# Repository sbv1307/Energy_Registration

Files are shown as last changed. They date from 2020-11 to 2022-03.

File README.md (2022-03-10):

# **Energy registration**
###### **Version 2.0.0**

This Arduino project will monitor the open collector output on a number of Carlo Gavazzi energy meters Type EM23 DIN and/or Type EM111.
The pulses will be counted and turned into number of kilo watt hours (kWh).

Upon request, the pulses counted (presented in kWh) will be pushed to a Google Sheet through a local webhook (A web site which basically "translate" HPPT to HTTPS).

Each meter monitored, will be connected to a digital imput, as well as the interrupt pin (See Emergy Registration Schematics.pdf for details).

Upon a HTTP GET pushToGoogle request (http://<Arduino IP address>/pushToGoogle), the sketch will return a HTML webpage, showing the current meter valeus, 
and initiate a HTTP GET request towards a local webHook, with the meter values, as the GET query values.

A HTTP GET meterValue request (http://<Arduino IP address>/meterValue) will return a webpage showing the current meter valeus.
 
A HTTP GET meterValue?meter<n>=<nn>, will set the counter to the provided value for the specified energy meter.
The value <n> represent the energy meter 1-7 and nn the actual energy meter value as readden on the meter, with two dicmals but entered without the decimal seperator!
(http://<Arduino IP address>/meterValue?meter1=1234567 will set the value for energy meter number one to 12345.67)

Notes:
The sketch monitors interrupt pin 2 for a FALLING puls and then reads the defined channelPins and register pulses for each pin.
The interruptfunction has a catch: It enters a "while pin 2 is low" loop, and stays there, until the interrupt is released.
This is against all recomendations, saying Interruptfunctions should be very short. 

However, in order to handle the problem with overlapping pulses from more meters, the interruptfunction will read the channels over and over,
without re-reading channels that allready has been read active (low). This way all pulses on all channels will be read.

Example: Tree meters generate tree pulses as shown below:
```bash
          _______        _______
Meter #1:        |______|
             _______        _______
Meter #2:           |______|
                _______        _______
Meter #3:              |______|

```
A pulse from meter #1 will activate the Interrupt Service Rutine (ISR), which startes the "while pin 2 is low" loop. When the pulse on meter #2 appears, while the pulse on meter #1 is still active, the ISR will stay active, when the puls on meter #1 dissapears. Then same happens when the pulse from meter #3 appears.
The "while pin 2 is low" loop read all non-read input pins, meaning: when a pin has been read as active (LOW), then pin will be read as readden, and wil not be re-read.

When the puls (the puls in meter #3) is released, the ISR ends. Then main loop will update the counter for each readden input pin, at reset the the status for the input pin.

 Version history:
  * 2.0.0 - Arduino SW project now merged with KiCad Hardware, and this version surpports the new HW design
 *         1 - LED_BUILTIN on Pin #9 has stopped woring. Pin A3 will be used instead. LED_PIN changed to LED_PIN - 
 *             HOWEVER!!! It has turned out, that it was set incrrrectly by the entrepreter. Hovering over the LED_BULTIN variable indicate it expands to 13 and not 9.
 *             Setting LED_PIN to 9, makes the LED light.
 *             Since the Hardware prototype, was made to use PIN 17, Pin 17 will be used for LED_PIN in this version.
 *         2 - Channels extenced to 8 instead of 7. Noe includeing Pin A2 
 * 0.2.3 - BUILTIN_LED has stopped working - NEED INVESTIGATION AND CODE IMPLEMTATION
 * 0.2.2 - Post powerup data to google sheets (data, and the comment (Power Up))
 * 0.2.1 - Cleaning up entries used for verifying pulscounts - No functional changes.
 * 0.2.0 - Meters, which only gives 100 pulses pr. kWh, were registered as if they gave a thousenth. Might be an issue by adding "1.000 / (double)PPKW[ii]" (0.01) to the previous counts.
 *         Since 1.000 / "(double)PPKW[ii]" might now be exactly 0.01 but maybe 0.009nnnnnnnnn, which could sum up the deffrence.
 *         SO - This version 0.2.0 will count pulses (integers). 
 *         Notes to be taken here - Mixing the types long and int, can give strange results (sometimes).
 *          - Implement: Remove SD update after each pulsecount, marked: "// V0.1.4_change (1)" in ver. 0.1.4
 *          - Implement: Flashing LED_BUILTI handled by calls to millis(), marked : "// V0.1.4_change (3)" in ver. 0.1.4.
 *          - SD Updates are done for every 10 pulses or every 30 minutes (only if pulses have been registred).
 * 0.1.4 - In an attempt to investigate lost registrations, writing every update to SD will be changed (changes marked // V0.1.4_change):
 *         1 - Remove SD update after each pulsecount marked: // V0.1.4_change (1)
 *         2 - SD is updated after each call to HTTP GET meterValue request (http://<Arduino IP address>/meterValue) marked: // V0.1.4_change (2)
 *         3 - Flashing the LED_BUILTI has handeled by the time it took to write to SD. Flashing LED_BUILTI will be handled by calls to millis() marked : // V0.1.4_change (3)
 * 
 * 0.1.3 - Due to capacity limitations in version 0.1.2, this version build upon version 0.1.1
 *       - This version is to trace why pulse registrations are lost.
 *       - Screesed in the HTML <form> element form Version 0.2.1 - Makes energymeter settings much easier
 *       - Dividing entered metervalues by 100, to avodi having to enter dicimal point (a dot) when enter metervalues
 *       - Corrected BUGs in getQuery(EthernetClient localWebClient)
 *       - Error dinvestigations marked: TO_BE_REMOVED
 *       - Added further #ifdef sections.
 *       - Inserted a function call to setMeterDataDefaults in function getQuery. If Metervalue for Meter 1 is nigative, metervalues are reset
 * 0.1.2 - N O T E !!!! - Changes exceeded limit for: Low memory available, stability problems may occur.
 *         Change in HTML presentation of energy meter values. Describing text. e.g. "Værksted" added to the informaiotn: "Meter <n>".
 *       - Introduces IP configuration for Arduino Ethernet shield attached to Arduino UNO. Define ARDUINO_UNO_DEBUG
 * 0.1.1 - Web server and web client funktionality added.
 * 0.1.0 - Initial commit - This versino is a merger of two lab tests: "EnergyRegistration" and "LocalWebHook-with-server-for-Arduino".

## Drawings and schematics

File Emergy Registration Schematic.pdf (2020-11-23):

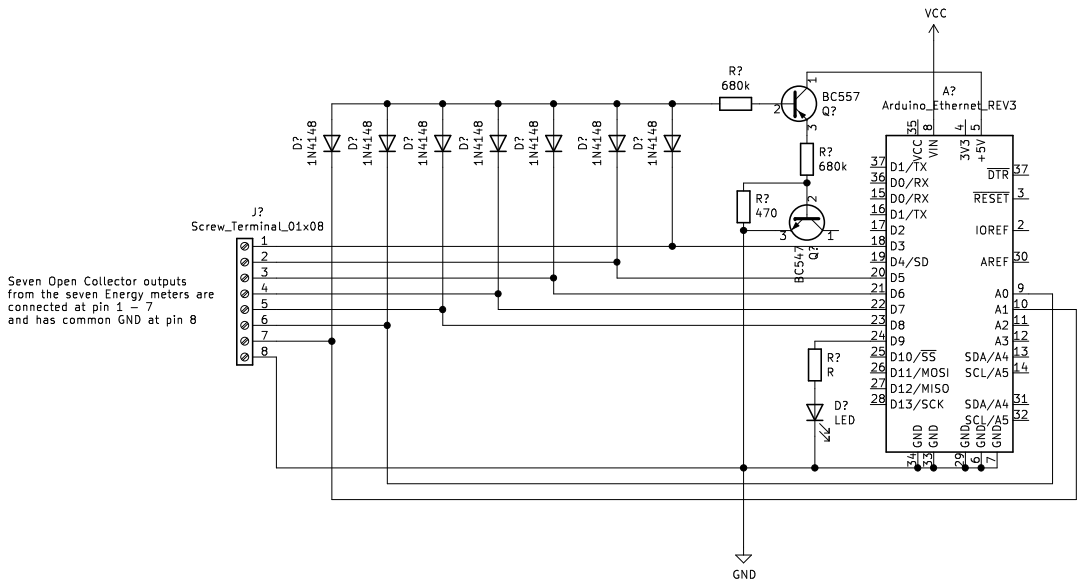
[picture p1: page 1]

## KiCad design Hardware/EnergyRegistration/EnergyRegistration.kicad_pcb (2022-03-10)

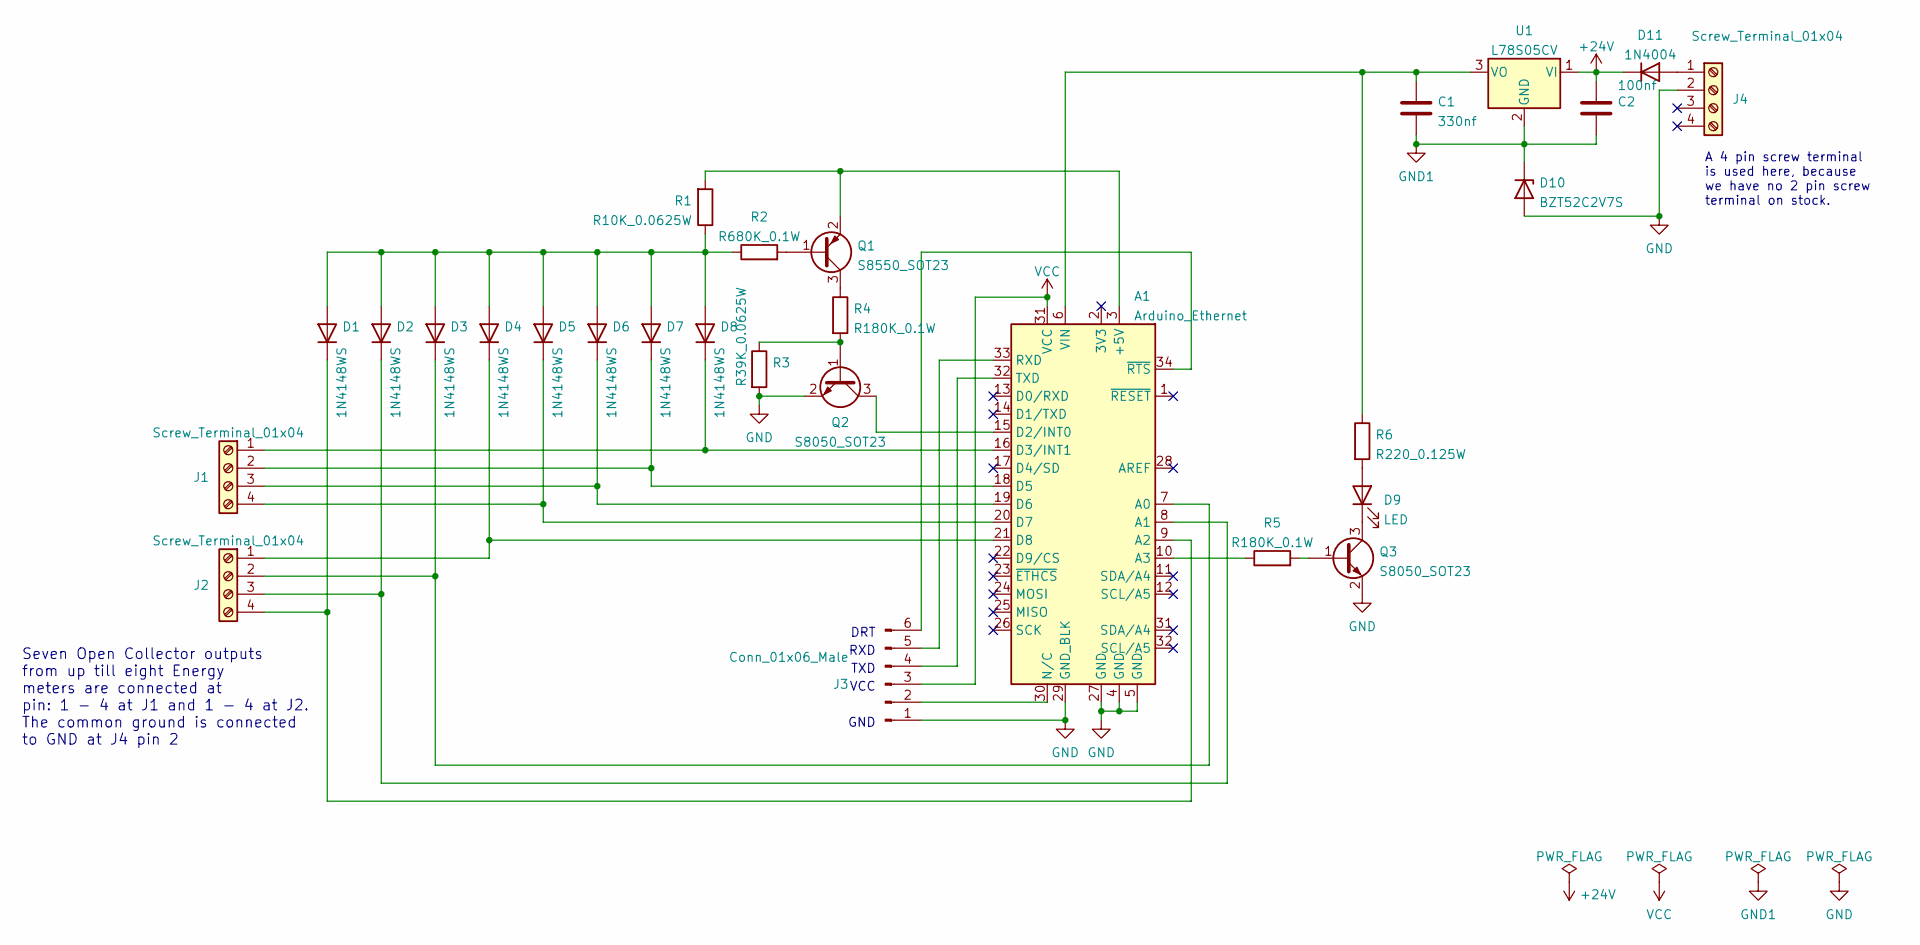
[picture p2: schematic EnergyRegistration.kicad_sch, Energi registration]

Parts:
A1: Arduino_Ethernet; Arduino_Ethernet_WithMountingHoles
C1: 330nf; C_0805_2012Metric; Manufacturer PN 0805B334K500NT; JLCPCB Part # C1740
C2: 100nf; C_0805_2012Metric; Manufacturer PN CC0805KRX7R9BB104; JLCPCB Part # C49678
D1, D2, D3, D4, D5, D6, D7, D8: 1N4148WS; D_SOD-323F; Manufacturer PN 1N4148WS; Digi-Key 1N4148WS-FDICT-ND
D9: LED; LED_D3.0mm; Manufacturer PN TJ-L3FYTGCGMCGLFLC2G-A5; JLCPCB Part # C331056
D10: BZT52C2V7S; D_SOD-123; Manufacturer PN BZT52C2V7S; JLCPCB Part # C353539
D11: 1N4004; D_DO-41_SOD81_P12.70mm_Horizontal; Manufacturer PN 1N4004B-G; Digi-Key Order no.: 641-1999-ND
J1, J2, J4: Screw_Terminal_01x04; TerminalBlock_PT-1,5-4-5.0-H_1x04_P5.00mm_Horizontal-(Front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
J3: Conn_01x06_Male; PinHeader_1x06_P_0,1in_Vertical
Q1: S8550_SOT23; SOT-23; Manufacturer PN S8550; JLCPCB Part # C105432
Q2, Q3: S8050_SOT23; SOT-23; Manufacturer PN SS8050; JLCPCB Part # C2150
R1: R10K_0.0625W; R_0603_1608Metric; Manufacturer PN 0402WGF1002TCE; JLCPCB Part # C25744
R2: R680K_0.1W; R_0603_1608Metric; Manufacturer PN 0603WAF6803T5E; JLCPCB Part # C25822
R3: R39K_0.0625W; R_0402_1005Metric; Manufacturer PN 0402WGF3902TCE; JLCPCB Part # C25783
R4, R5: R180K_0.1W; R_0603_1608Metric; Manufacturer PN 0603WAF1803T5E; JLCPCB Part # C22827
R6: R220_0.125W; R_0805_2012Metric; Manufacturer PN 0805W8F2200T5E; JLCPCB Part # C17557
U1: L78S05CV; TO-220-3_Vertical; Digi-Key Order no.: 497-14164-ND

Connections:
+24V: C2.1, D11.1 (K), U1.1 (VI)
GND: A1.4 (GND), A1.5 (GND), A1.27 (GND), A1.29 (GND_BLK), D10.2 (A), J3.1, J4.2, Q2.2 (E), Q3.2 (E), R3.2
GND1: C1.2, C2.2, D10.1 (K), U1.2 (GND)
unnamed: A1.3 (+5V), Q1.2 (E), R1.2
unnamed: A1.6 (VIN), C1.1, R6.1, U1.3 (VO)
unnamed: A1.7 (A0), D3.1 (K), J2.2
unnamed: A1.8 (A1), D2.1 (K), J2.3
unnamed: A1.9 (A2), D1.1 (K), J2.4
unnamed: A1.10 (A3), R5.1
unnamed: A1.15 (D2/INT0), Q2.3 (C)
unnamed: A1.16 (D3/INT1), D8.1 (K), J1.1
unnamed: A1.18 (D5), D7.1 (K), J1.2
unnamed: A1.19 (D6), D6.1 (K), J1.3
unnamed: A1.20 (D7), D5.1 (K), J1.4
unnamed: A1.21 (D8), D4.1 (K), J2.1
unnamed: A1.30 (N/C), J3.2
unnamed: A1.32 (TXD), J3.4
unnamed: A1.33 (RXD), J3.5
unnamed: A1.34 (~RTS), J3.6
unnamed: D1.2 (A), D2.2 (A), D3.2 (A), D4.2 (A), D5.2 (A), D6.2 (A), D7.2 (A), D8.2 (A), R1.1, R2.1
unnamed: D9.1 (K), Q3.3 (C)
unnamed: D9.2 (A), R6.2
unnamed: D11.2 (A), J4.1
unnamed: Q1.1 (B), R2.2
unnamed: Q1.3 (C), R4.1
unnamed: Q2.1 (B), R3.1, R4.2
unnamed: Q3.1 (B), R5.2
VCC: A1.31 (VCC), J3.3

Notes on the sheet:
Seven Open Collector outputs from up till eight Energy meters are connected at pin: 1 - 4 at J1 and 1 - 4 at J2. The common ground is connected to GND at J4 pin 2
A 4 pin screw terminal is used here, because we have no 2 pin screw terminal on stock.
RXD
DRT
VCC
TXD
GND

Board: 2 copper layers, 28 parts (0 on the bottom side), 27 nets, no tracks yet.

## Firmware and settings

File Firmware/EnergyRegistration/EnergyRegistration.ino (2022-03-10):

/* Verify (compile) for Arduino Ethernet
 *  
 *  
 *  
 * This sketch reads an open collector output on a number of Carlo Gavazzi energy meters Type EM23 DIN and/or Type EM111.
 * The sketch monitors interrupt pin 2 for a FALLING puls and then reads the defined channelPins and counts pulses for each pin.
 * 

 * Upon a HTTP GET request "http://<Arduino IP address>/pushToGoogle", the sketch will return a webpage, showing the current meter valeus, 
 * and initiate a HTTP GET request towards a webHook (webHookServer), with the meter values, as the GET query values. 
 * Due to limited capacity the HTTP GET request for the webHook is hardcoded in this version. The request is:
 * GET /energyRegistrations/updateEnergyRegistrations?function=updateSheet&dataString=<Value for meter 1>,<Value for meter 2>,....<Value for meter7>
 * http://192.168.10.102/energyRegistrations/updateEnergyRegistrations?function=updateSheet&dataString=279.97,752.04,260.03,441.21,806.67,1.08,3362.79
 * 
 * A HTTP GET meterValue request "http://<Arduino IP address>/meterValue" will return a webpage showing the current meter valeus.
 * 
 * A HTTP GET meterValue?meter<n>=<nn>, where <n> represent the energy meter 1-7 and nn the actual energy meter value as readden on the meter. 
 * Then meter value will eb entered with two dicimals, but without the decimal seperator.
 * To set energy meter number 1 to 12345,67, pass the following HTTP GET request: http://<Arduino IP address>/meterValue?meter1=1234567
 * 
 * IP address is hardcoded to reduce memory requirement.
 * 
 * For this sketch on privat network 192.168.10.0 and Ardhino IP address 192.168.10.146 some recogniced requests are:
 * http://192.168.10.146/pushToGoogle
 * http://192.168.10.146/meterValue
 * http://192.168.10.146/meterValue?meter1=1234567
 * 
 * The code is made specific for the Arduino Ethernet REV3 board.
 * 
 * Created:
 * 2020-11-19
 */

#define SKETCH_VERSION "Carlo Gavazzi energy meter Type EM23 and/or Type EM111 DIN - Energy registrations - V2.0.0"


/*
 * Future modifications / add-on's
 * - Re-define which PIN are to be used for LED. Considerations:
 *   1: BuiltIn LED is hardwired to PIN 9
 *   2: Pin 9 is a digital pin, suitable for input.
 * - When HTTP request has no or incorrect abs-path / function - load explnating HTML page for corret usage
 * - Make webHookServer IP address an port number configurable.
 *
 * 2.0.0 - Arduino SW project now merged with KiCad Hardware, and this version surpports the new HW design
 *         1 - LED_BUILTIN on Pin #9 has stopped woring. Pin A3 will be used instead. LED_PIN changed to LED_PIN - 
 *             HOWEVER!!! It has turned out, that it was set incrrrectly by the entrepreter. Hovering over the LED_BULTIN variable indicate it expands to 13 and not 9.
 *             Setting LED_PIN to 9, makes the LED light.
 *             Since the Hardware prototype, was made to use PIN 17, Pin 17 will be used for LED_PIN in this version.
 *         2 - Channels extenced to 8 instead of 7. Noe includeing Pin A2 
 * 0.2.3 - BUILTIN_LED has stopped working - NEED INVESTIGATION AND CODE IMPLEMTATION
 * 0.2.2 - Post powerup data to google sheets (data, and the comment (Power Up))
 * 0.2.1 - Cleaning up entries used for verifying pulscounts - No functional changes.
 * 0.2.0 - Meters, which only gives 100 pulses pr. kWh, were registered as if they gave a thousenth. Might be an issue by adding "1.000 / (double)PPKW[ii]" (0.01) to the previous counts.
 *         Since 1.000 / "(double)PPKW[ii]" might now be exactly 0.01 but maybe 0.009nnnnnnnnn, which could sum up the deffrence.
 *         SO - This version 0.2.0 will count pulses (integers). 
 *         Notes to be taken here - Mixing the types long and int, can give strange results (sometimes).
 *          - Implement: Remove SD update after each pulsecount, marked: "// V0.1.4_change (1)" in ver. 0.1.4
 *          - Implement: Flashing LED_BUILTI handled by calls to millis(), marked : "// V0.1.4_change (3)" in ver. 0.1.4.
 *          - SD Updates are done for every 10 pulses or every 30 minutes (only if pulses have been registred).
 * 0.1.4 - In an attempt to investigate lost registrations, writing every update to SD will be changed (changes marked // V0.1.4_change):
 *         1 - Remove SD update after each pulsecount marked: // V0.1.4_change (1)
 *         2 - SD is updated after each call to HTTP GET meterValue request (http://<Arduino IP address>/meterValue) marked: // V0.1.4_change (2)
 *         3 - Flashing the LED_BUILTI has handeled by the time it took to write to SD. Flashing LED_BUILTI will be handled by calls to millis() marked : // V0.1.4_change (3)
 * 
 * 0.1.3 - Due to capacity limitations in version 0.1.2, this version build upon version 0.1.1
 *       - This version is to trace why pulse registrations are lost.
 *       - Screesed in the HTML <form> element form Version 0.2.1 - Makes energymeter settings much easier
 *       - Dividing entered metervalues by 100, to avodi having to enter dicimal point (a dot) when enter metervalues
 *       - Corrected BUGs in getQuery(EthernetClient localWebClient)
 *       - Error dinvestigations marked: TO_BE_REMOVED
 *       - Added further #ifdef sections.
 *       - Inserted a function call to setMeterDataDefaults in function getQuery. If Metervalue for Meter 1 is nigative, metervalues are reset
 * 0.1.2 - N O T E !!!! - Changes exceeded limit for: Low memory available, stability problems may occur.
 *         Change in HTML presentation of energy meter values. Describing text. e.g. "Værksted" added to the informaiotn: "Meter <n>".
 *       - Introduces IP configuration for Arduino Ethernet shield attached to Arduino UNO. Define ARDUINO_UNO_DEBUG
 * 0.1.1 - Web server and web client funktionality added.
 * 0.1.0 - Initial commit - This versino is a merger of two lab tests: "EnergyRegistration" and "LocalWebHook-with-server-for-Arduino".
 * 
 * 
 * 
 **** Ardhino Ethernet REV3 Pin definition/layout:***
 * Pin  0: Serial RX
 * Pin  1: Serial TX
 * Pin  2: Interrupt pin for counting pulses.
 * Pin  3: Channel pin 1: Input for reading Open Collector output on Type EM111 DIN energy meter (1000 pulses per kWh (PPKW))
 * Pin  4: Chip select (CS) for SD card (Disable SD card if not used - Undefined SD card could cause problems with the Ethernet interface.)
 * Pin  5: Channel pin 2: Input for reading Open Collector output on Type EM111 DIN energy meter (1000 pulses per kWh)
 * Pin  6: Channel pin 3: Input for reading Open Collector output on Type EM111 DIN energy meter (1000 pulses per kWh)
 * Pin  7: Channel pin 4: Input for reading Open Collector output on Type EM111 DIN energy meter (1000 pulses per kWh)
 * Pin  8: Channel pin 5: Input for reading Open Collector output on Type EM111 DIN energy meter (1000 pulses per kWh)
 * Pin  9: Default defined as LED_BUILTIN. NOT WORKING because LED_BUILTIN is defined as PIN 13. Now re-defined as PIN 17 
 * Pin 10: Chip select (CS) for SD card.
 * Pin 11: SPI.h library for MOSI (Master In Slave Out) 
 * Pin 12: SPI.h library for MISO (Master Out Slave In)
 * Pin 13: SPI.h library for SCK (Serial Clock).
 * Pin 14 (A0): Channel pin 6: Input for reading Open Collector output on Type EM23 DIN energy meter (100 pulses per kWh)
 * Pin 15 (A1): Channel pin 7: Input for reading Open Collector output on Type EM23 DIN energy meter (100 pulses per kWh)
 * Pin 16 (A2): Channel pin 8: Input for reading Open Collector output on Type EM23 DIN energy meter (100 pulses per kWh)
 * Pin 17 (A3): Defined as LED_PIN used for indicating pulsecounts and other activity (powerUP or failure to bootup) (Replaces defective  definition of LED_BUILTIN)
 * Pin 18 (A4):
 * Pin 19 (A5):
 */



/* 
 * The interruptfunction has a catch: It enters a "while pin 2 is low" loop, and stays there, until the interrupt is released. 
 * Se further explanation in the README.md file.
 * 
 * Values are stored on SD in order to prevent too much data loss in case of a poweroutage or reststart. 
 * In order ot prevent SC update for every signle pulse registred, Updates are done for every 10 pulses or every 30 minutes 
 * (only if pulses have been registred)
 * 
 */
#include <SPI.h> 
#include <SD.h> 
#include "SDAnything.h"
#include <Ethernet.h>
#include <SPI.h>


/*
 * ######################################################################################################################################
 *                                    D E F I N E    D E G U G G I N G
 * ######################################################################################################################################
*/
//#define DEBUG        // If defined (remove // at line beginning) - Sketch await serial input to start execution, and print basic progress 
                       //   status informations
//#define WEB_DEBUG    // (Require definition of  DEBUG!) If defined - print detailed informatins about web server and web client activities
//#define COUNT_DEBUG  // (Require definition of  DEBUG!)If defined - print detailed informatins about puls counting. 
//#define ARDUINO_UNO_DEBUG  //If defined: MAC and IP address will be set accoring to the MAC address for the Arduino Ethernet shield
/*
 * ######################################################################################################################################
 *                       C  O  N  F  I  G  U  T  A  B  L  E       D  E  F  I  N  I  T  I  O  N  S
 * ######################################################################################################################################
*/

#define DATA_STRUCTURE_VERSION 2    // Version number to verify if data read from file corrospond to current structure defination.
#define DATA_FILE_NAME "data.dat"  //The SD Library uses short 8.3 names for files. 

#define NO_OF_CHANNELS 8                                                // Number of energy meters connected
const int channelPin[NO_OF_CHANNELS] = {3,5,6,7,8,14,15,16};               // define which pin numbers are used for input channels
const int PPKW[NO_OF_CHANNELS] = {1000,1000,1000,1000,1000,100,100,100};    //Variable for holding Puls Pr Kilo Watt (PPKW) for each channel (energy meter)

#define SD_UPDATE_COUNTS 50              // Define how many pules to regisgter, before storing counts to SD Card
#define TIME_BETWEEN_SD_UPDATES 1800000  // Time in millisecunds: 30 min = 30 x 60 x 1000 = 1800000 ms

#define INTERRUPT_PIN 2
#define CHIP_SELECT_PIN 4
#define LED_BUILTIN 17
#define HTTP_PORT_NUMBER 80
#define ONBOARD_WEB_SERVER_PORT 80

/*
 * Incapsulate strings i a P(string) macro definition to handle strings in PROGram MEMory (PROGMEM) to reduce valuable memory  
  MACRO for string handling from PROGMEM
  https://todbot.com/blog/2008/06/19/how-to-do-big-strings-in-arduino/
  max 149 chars at once ...
*/
char p_buffer[150];
#define P(str) (strcpy_P(p_buffer, PSTR(str)), p_buffer)

                                                                    #ifdef  ARDUINO_UNO_DEBUG  //overwrite configuration for Arduino Ethernet REV3 board
                                                                      byte mac[] = { 0x90, 0xA2, 0xDA, 0x0D, 0x34, 0xF9};  //Ethernet Shield (Arduino)
                                                                      IPAddress ip( 192, 168, 10, 123); // Ethernet Shield (Arduino)               
                                                                    #else
byte mac[] = { 0x90, 0xA2, 0xDA, 0x0D, 0x63, 0x15 };  // MAC address for Arduino Ethernet REV3 board
IPAddress ip( 192, 168, 10, 146);                     // IP address for Arduino Ethernet REV3 board
                                                                    #endif
IPAddress webHookServer( 192, 168, 10, 102);          // Local IP address for web server on QNAP-NAS-2 (192.168.10.x) NAP-NAS-2 

EthernetClient webHookClient;
EthernetServer localWebServer(ONBOARD_WEB_SERVER_PORT);

/*
 *  #####################################################################################################################
 *                       V  A  R  I  A  B  L  E      D  E  F  I  N  A  I  T  O  N  S
 *  #####################################################################################################################
 */
unsigned long led_Buildin_On;

int SD_WriteCounter;            // Counter used to dertermine when meterData are to be writen to SD
unsigned long SD_LastUpdated;   // Timer used to determine when meterData are to be writen to SD

/*
 * Define structure for energy meter counters
 * A remark for using the type (long) for counters. Using (int) would have been suficient, as metervaluse cannnot be
 * larger than 99999.99.
 * Howerver the choosen method of manually updating meter values, using the Arduino Ethernet library and the Serial.parseint(),
 * to parse the intered meter value from the ethernet stream, parsing the value as (long).
 * Experience showed that; "(int)variable = Serial.parseint();" did not work. The same for various attempts to convert (long) to (int).
 * Using (long) was simply the easies solution, all thoug it requires more RAM.
 */
struct data_t
   {
     int structureVersion;
     long pulseTotal[NO_OF_CHANNELS];    // For counting total number of pulses on each Chanel
     long pulsePeriod[NO_OF_CHANNELS];   // For counting number of pulses betseen every e-mail update (day) on each chanel
   } meterData;

volatile boolean channelState[NO_OF_CHANNELS];  // Volatile global vareiable used in interruptfunction

/*
 * ###################################################################################################
 *                       F  U  N  C  T  I  O  N      D  E  F  I  N  I  T  I  O  N  S
 * ###################################################################################################
*/
/*
 * >>>>>>>>>>>>>>>>>   S E T     C O N F I G U R A T I O N   D E F A U L T S  <<<<<<<<<<<<<<<<<<<<<<<<
 * Configuration is "hardcoded" to minimize sketch size
 */

/*
 * >>>>>>>>>>>>>>>>>   S E T     M E T E R   D A T A     D E F A U L T   <<<<<<<<<<<<<<<<<<<<<<<<<<<<<
 * 
 * Inititialize the meterData structure and store it to SD Card.
 */
void setMeterDataDefaults() {
    meterData.structureVersion = 10 * DATA_STRUCTURE_VERSION + NO_OF_CHANNELS;
    for (int ii = 0; ii < NO_OF_CHANNELS; ii++) {
      meterData.pulseTotal[ii] = 0;
      meterData.pulsePeriod[ii] = 0;
    }
  int characters = SD_reWriteAnything(DATA_FILE_NAME, meterData);
}
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
void loop() {
  boolean reqToPush = false;
/*
 * >>>>>>>>>>>>>>>>>>>>>>>>>  C o u n i n g    m o d u l e   -   B E G I N     <<<<<<<<<<<<<<<<<<<<<<<
 * >>>>>>>>>>>>>>>>>>>>>>>>>>>>>>>>>>>>>>>>>>>>>>>>>><<<<<<<<<<<<<<<<<<<<<<<<<<<<<<<<<<<<<<<<<<<<<<<<<<<<<<
 */

 
  for (int ii = 0; ii < NO_OF_CHANNELS; ii++) {
    if ( !channelState[ii]) {
      channelState[ii] = HIGH;
      led_Buildin_On = millis();
      digitalWrite(LED_BUILTIN, HIGH);

      SD_WriteCounter++;

      meterData.pulseTotal[ii]++;
      meterData.pulsePeriod[ii]++;
                                                              #ifdef COUNT_DEBUG
                                                              if ( ii == 0)
                                                                Serial.println();
                                                              Serial.print(P("Total pulses / kWh for channel "));
                                                              Serial.print( ii +1);
                                                              Serial.print(P(": "));
                                                              Serial.print(meterData.pulseTotal[ii]);
                                                              Serial.print(P(" / "));
                                                              double meterTotal = (double)meterData.pulseTotal[ii] / (double)PPKW[ii];
                                                              Serial.println(meterTotal, 3);
                                                              #endif
    }
  }

/*
 * >>>>>>>>>>>>>>>>>>>>>>>>>  C o u n i n g    m o d u l e   -   E N D      <<<<<<<<<<<<<<<<<<<<<<<<<<<<<<<
 * >>>>>>>>>>>>>>>>>>>>>>>>>>>>>>>>>>>>>>>>>>>>>>>>>><<<<<<<<<<<<<<<<<<<<<<<<<<<<<<<<<<<<<<<<<<<<<<<<<<<<<<
 */


  if (millis() > led_Buildin_On + (long)150)
    digitalWrite(LED_BUILTIN, LOW);
  
  if ( SD_WriteCounter >= SD_UPDATE_COUNTS  || millis() > SD_LastUpdated + TIME_BETWEEN_SD_UPDATES && SD_WriteCounter > 0 ) {
    int characters = SD_reWriteAnything(DATA_FILE_NAME, meterData);
    SD_WriteCounter = 0;
    SD_LastUpdated = millis();
  }

/*
 * >>>>>>>>>>>>>>>>>>>>>>>>>> W E B     S E R V E R     B E G I N    <<<<<<<<<<<<<<<<<<<<<<<<<<<<<<<<<<<<<<
 * >>>>>>>>>>>>>>>>>>>>>>>>>>>>>>>>>>>>>>>>>>>>>>>>>><<<<<<<<<<<<<<<<<<<<<<<<<<<<<<<<<<<<<<<<<<<<<<<<<<<<<<
 */
  EthernetClient localWebClient = localWebServer.available();
  
  if (localWebClient) {
    char keyWord1[14] = "pushToGoogle";
    int  keyWordPtr1 = 0;
    char keyWord2[12] = "meterValue";
    int  keyWordPtr2 = 0;
    while (localWebClient.connected())     {
      if (localWebClient.available()) {
        char c = localWebClient.read();
                                                              #ifdef WEB_DEBUG
                                                              Serial.print(c);
                                                              #endif

        if ( c == '\n') {
                                                              #ifdef WEB_DEBUG
                                                              Serial.println("\n\n>> New Line found - no further entreputation done\n\n");
                                                              #endif
          break;
        }

        if ( c == keyWord1[keyWordPtr1] )        // analize characterstream for presence of keyWord1 "pushToGoogle"
          keyWordPtr1++;
        else
          keyWordPtr1 = 0;

        if ( c == keyWord2[keyWordPtr2] )        // analize characterstream for presence of keyWord2 "meterValue"
          keyWordPtr2++;
        else
          keyWordPtr2 = 0;
      }

      
      if ( keyWordPtr1 == 12 || keyWordPtr2 == 10 ) {   // 12 / 10  på hinanden følgende karakterer i "keyWord" er fundet
        if ( keyWordPtr1 == 12) {
          reqToPush = true;                       // need to finish current web corrosponcence before pushing updates to wards Google. Setting flag to push data to webHook when finished.
        } else {
          char c = localWebClient.read();
          if ( c == '?') {                  //A "?" after the keyword/ function (abs_path) indicate a meterValue has a quey. A meter number and value-
            getQuery(localWebClient);
          }
        }

        // "200 OK" means the resource was located on the server and the browser (or service consumer) should expect a happy response
                                                              #ifdef WEB_DEBUG
                                                              Serial.println(P("\n\nGot Keyword sending: 200 OK\n"));
                                                              #endif
/*        
 *   Send a standard http response header
 */
        localWebClient.println(P("HTTP/1.1 200 OK"));
        localWebClient.println(P("Content-Type: text/html"));
        localWebClient.println(P("Connnection: close")); // do not reuse connection
        localWebClient.println();
          
/* 
 *  send html page, displaying meter values:
 *  
 *  
 */

                                                              #ifdef WEB_DEBUG
                                                              Serial.println(P("\nSend htmp page, displaying values\n"));
                                                              #endif

        if ( reqToPush == true)
          localWebClient.println(P("<HTML><head><title>PostToGoogle</title></head><body><h1>Posting following to Google Sheets</h1>"));
        else
          localWebClient.println(P("<HTML><head><title>MeterValues</title></head><body><h1>Energy meter values</h1>"));

        for ( int ii = 0; ii < NO_OF_CHANNELS; ii++) {

          localWebClient.println(P("<br><b>Meter </b>"));
          localWebClient.println(ii + 1);
          localWebClient.println(P("<b>:  </b>"));
          double meterTotal = (double)meterData.pulseTotal[ii] / (double)PPKW[ii];
          localWebClient.println(meterTotal);
          localWebClient.print(P("<form action='/meterValue?' method='GET'>New value: <input type=text name='meter"));
          char meter[2];
          sprintf(meter, "%i", ii + 1);
          localWebClient.print(meter);
          localWebClient.println(P("'/> <input type=submit value='Opdater'/></form>"));
// No endtag for <br> !?          localWebClient.println(P("</br>"));


        }
        // max length:    -----------------------------------------------------------------------------------------------------------------------------------------------------  (149 chars)
        localWebClient.println(P("</body></html>"));

        // Exit the loot
        break;
      }
    }

/*    
 *     Not verified if localWebClient.flush() actually empties the stream, therefor explicite read all characters.
 */
    while ( localWebClient.available()) {
      char c = localWebClient.read();
    }
    localWebClient.flush();
    localWebClient.stop();
  }  //>>>>>>>>>>>>>>>>>>>>>>> W E B     S E R V E R     E N D    <<<<<<<<<<<<<<<<<<<<<<<<<<<<<<<<<<<<<<

  /*
   * >>>>>>>>>>>>>>>>>>> U P D A T E     G O O G L E   S H E E T S    <<<<<<<<<<<<<<<<<<<<<<<<<<<<<<<<<<
   */
  if ( reqToPush == true) {
    boolean powerOn = false;
    updateGoogleSheets( powerOn);
  }
}

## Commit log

2020-11-20 Initial Commit Setup() and Counting module (incl. interrupt funktionality
2020-11-23 * 0.1.2 - N O T E !!!! - Changes exceeded limit for: Low memory available, stability problems may occur. * Change in HTML presentation of energy meter values. Describing text. e.g. "Værksted" added t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
    [EnergyRegistration.ino]
2020-11-25 * 0.1.3 - Due to capacity limitations, this version build upon version 0.1.1 * - This version is to trace why pulse registrations are lost. * - Screesed in the HTML <form> element form Version 0.2.1 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
    [MissedCountStatistics.ods]
2020-11-26 Bug - forgot to reset pulseRegistered, which obvious causes an incorrectg count.
    [MissedCountStatistics.ods]
2022-01-26 Ver. 0.1.4 - removing SD updates did not solve the issue
    [EnergyRegistration.ino]
2022-01-31 remote arduino json from repo
2022-01-31 Debug entries removed
    [MissedCountStatistics.ods]
2022-02-18 Arduino and KiCad projects merged into one filestructure
    [EnergyRegistration.kicad_pcb, EnergyRegistration.kicad_sch]
2022-02-19 Vorking commit
    [EnergyRegistration.kicad_sch]
2022-03-09 PCB Components added
    [EnergyRegistration.kicad_pcb, EnergyRegistration.kicad_sch]
2022-03-09 Library update
    [EnergyRegistration.kicad_pcb, EnergyRegistration.kicad_sch]
2022-03-09 fix: Change pinnumber for LED to PIN 17
    [EnergyRegistration.ino]
2022-03-10 Components changed to SMD
    [EnergyRegistration.kicad_pcb, EnergyRegistration.kicad_sch]
